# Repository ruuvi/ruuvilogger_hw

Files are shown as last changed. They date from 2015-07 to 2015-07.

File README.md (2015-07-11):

# RuuviLogger: Open-Source GPS logging device

You can find RuuviLogger related hardware design files from this repository. Design is almost finished, but not 100% ready. If RuuviLogger project continues, Rev.A version will be probably deprecated.

All the design files are licensed under Attribution-ShareAlike 4.0 International (CC BY-SA 4.0). Copyright: Lauri Jämsä, Ruuvi Innovations Ltd.

More info (a few blog posts) about the project: http://ruuvi.com/blog

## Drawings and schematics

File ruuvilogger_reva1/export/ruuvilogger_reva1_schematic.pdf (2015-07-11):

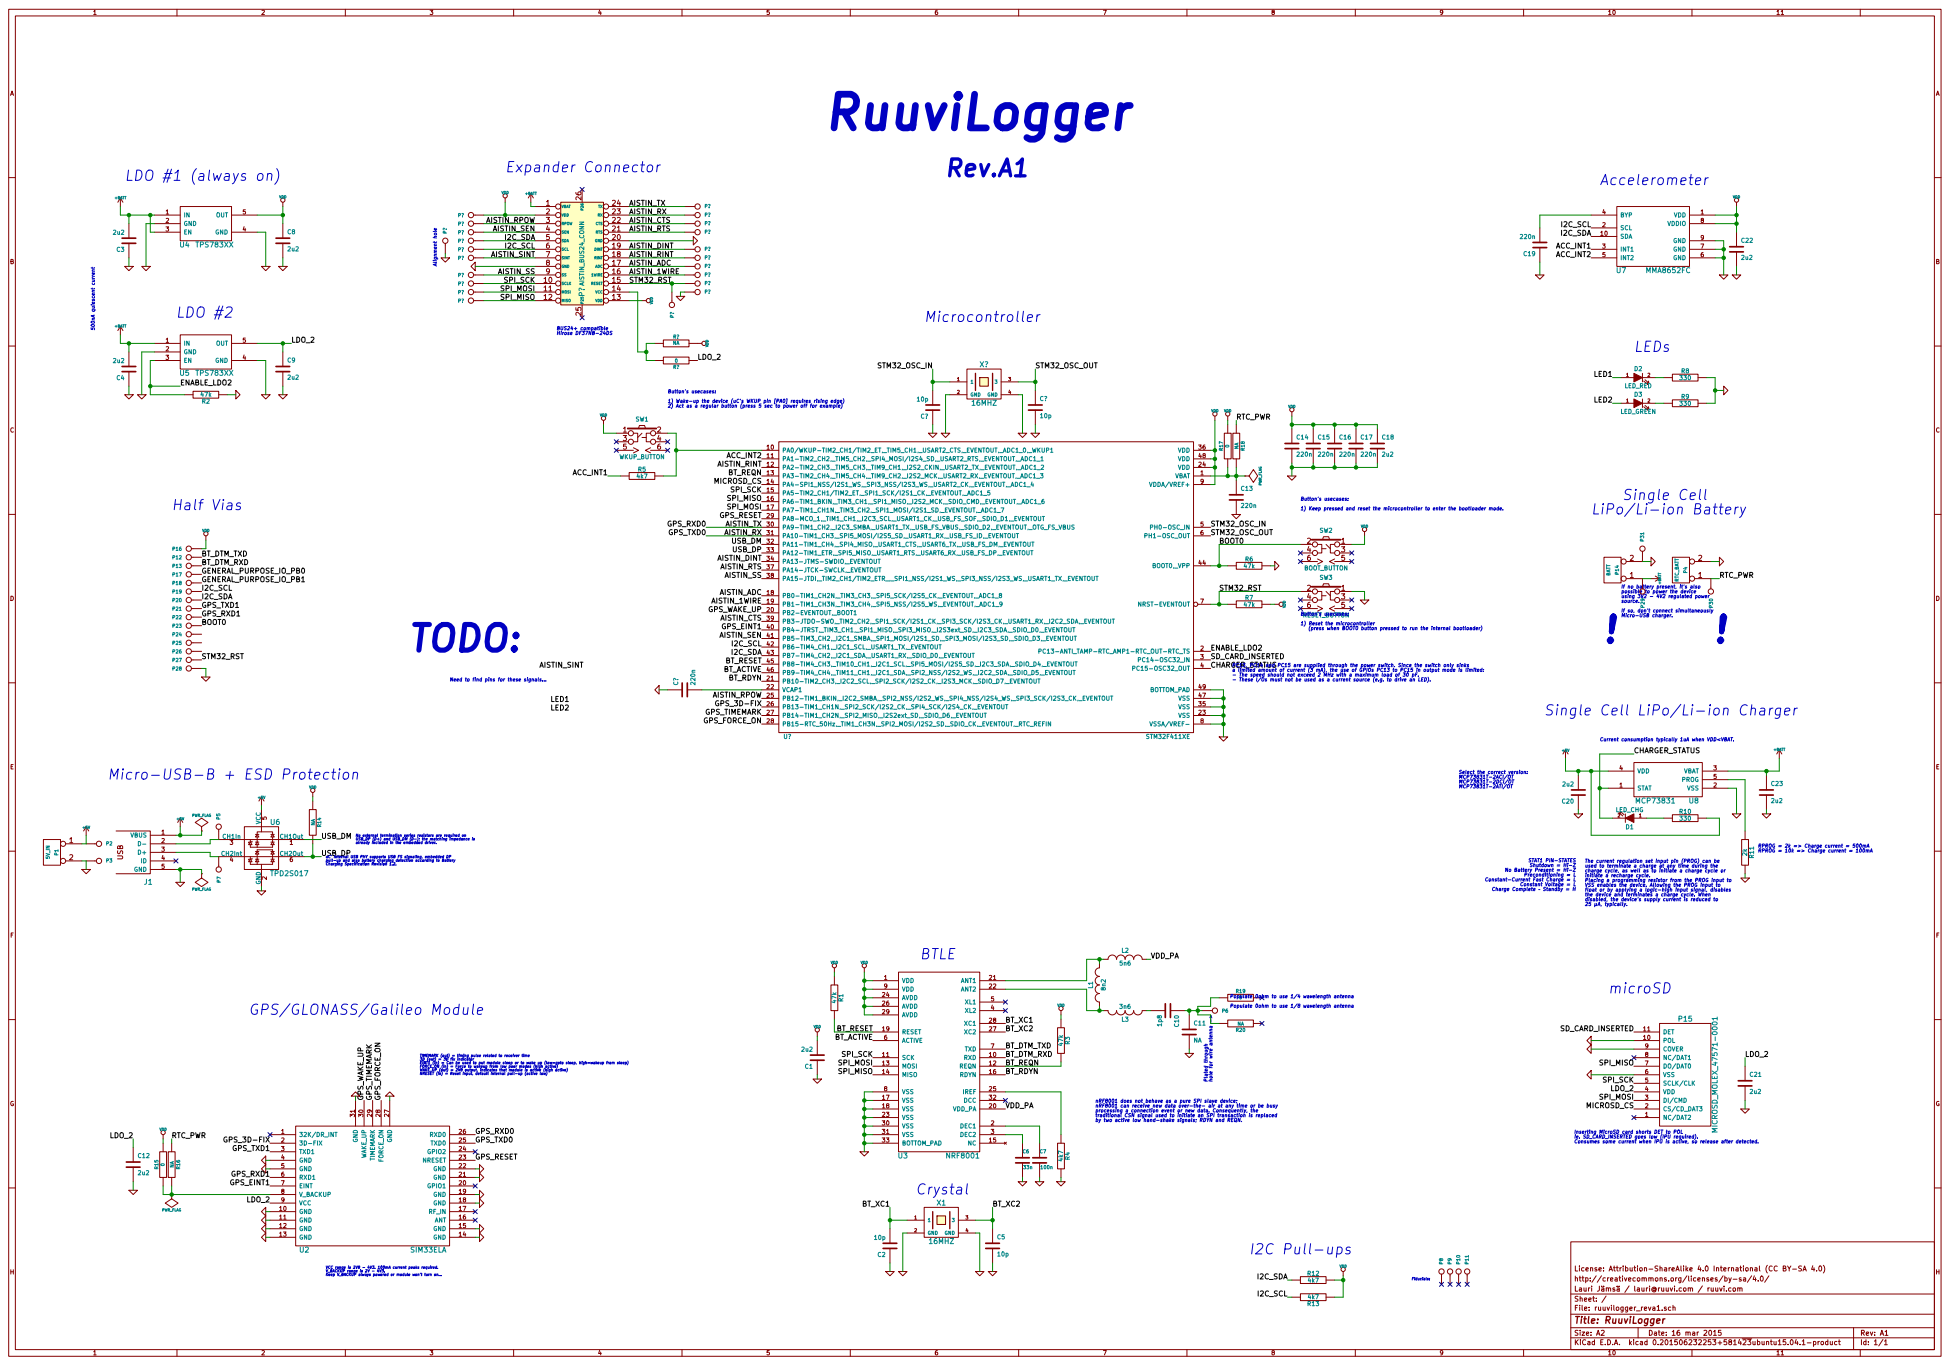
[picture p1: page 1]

PC13, PC14 and PC15 are supplied through the power switch. Since the switch only sinks a limited amount of current (3 mA), the use of GPIOs PC13 to PC15 in output mode is limited: - The speed should not exceed 2 MHz with a maximum load of 30 pF. - These I/Os must not be used as a current source (e.g. to drive an LED). STM32_OSC_OUT

If so, don't connect simultaneously Micro-USB charger. Single Cell
LiPo/Li-ion Battery

(press when BOOT0 button pressed to run the internal bootloader) Button's usecases: 1) Keep pressed and reset the microcontroller to enter the bootloader mode. Need to find pins for these signals... GPS_RXD1

If no battery present, it's also
possible to power the device
using 3V2 - 4V2 regulated power source.

Button's usecases: 1) Reset the microcontroller

Single Cell LiPo/Li-ion Charger

Micro-USB-B + ESD Protection

USB_DP
uC' internal USB PHY supports USB FS signaling, embedded DP
pull-up and also battery charging detection according to Battery Charging Specification Revision 1.2.

The current regulation set input pin (PROG) can be
used to terminate a charge at any time during the
charge cycle, as well as to initiate a charge cycle or
initiate a recharge cycle. Placing a programming resistor from the PROG input to VSS enables the device. Allowing the PROG input to

float or by applying a logic-high input signal, disables
the device and terminates a charge cycle. When
disabled, the devices supply current is reduced to

Populate 0ohm to use 1/4 wavelength antenna Populate 0ohm to use 1/8 wavelength antenna Plated through hole for wire antenna ->

GPS/GLONASS/Galileo Module

ie. SD_CARD_INSERTED goes low (IPU required). Consumes some current when IPU is active, so release after detected. SD_CARD_INSERTED

by two active low hand-shake signals; RDYN and REQN. BT_DTM_TXD
BT_DTM_RXD
BT_REQN
BT_RDYN

TIMEMARK (out) = timing pulse related to receiver time
3D (out) = 3D fix indicator EINT1 (in) = Can be used to put module sleep or to wake up (low=goto sleep, high=wakeup from sleep) FORCE_ON (in) = Force to wakeup from low poer modes (high active) WAKE_UP (out) = 2V8 output, indicates that module is active (high active) NRESET (in) = Reset input, default internal pull-up (active low)

nRF8001 does not behave as a pure SPI slave device; nRF8001 can receive new data over-the- air at any time or be busy processing a connection event or new data. Consequently, the

traditional CSN signal used to initiate an SPI transaction is replaced

Inserting MicroSD card shorts DET to POL

VCC range is 2V8 - 4V3. 100mA current peaks required. V_BACKUP range is 2V - 4V3. Keep V_BACKUP always powered or module won't turn on...

License: Attribution-ShareAlike 4.0 International (CC BY-SA 4.0)
http://creativecommons.org/licenses/by-sa/4.0/
File: ruuvilogger_reva1.sch Sheet: / Lauri Jämsä / lauri@ruuvi.com / ruuvi.com

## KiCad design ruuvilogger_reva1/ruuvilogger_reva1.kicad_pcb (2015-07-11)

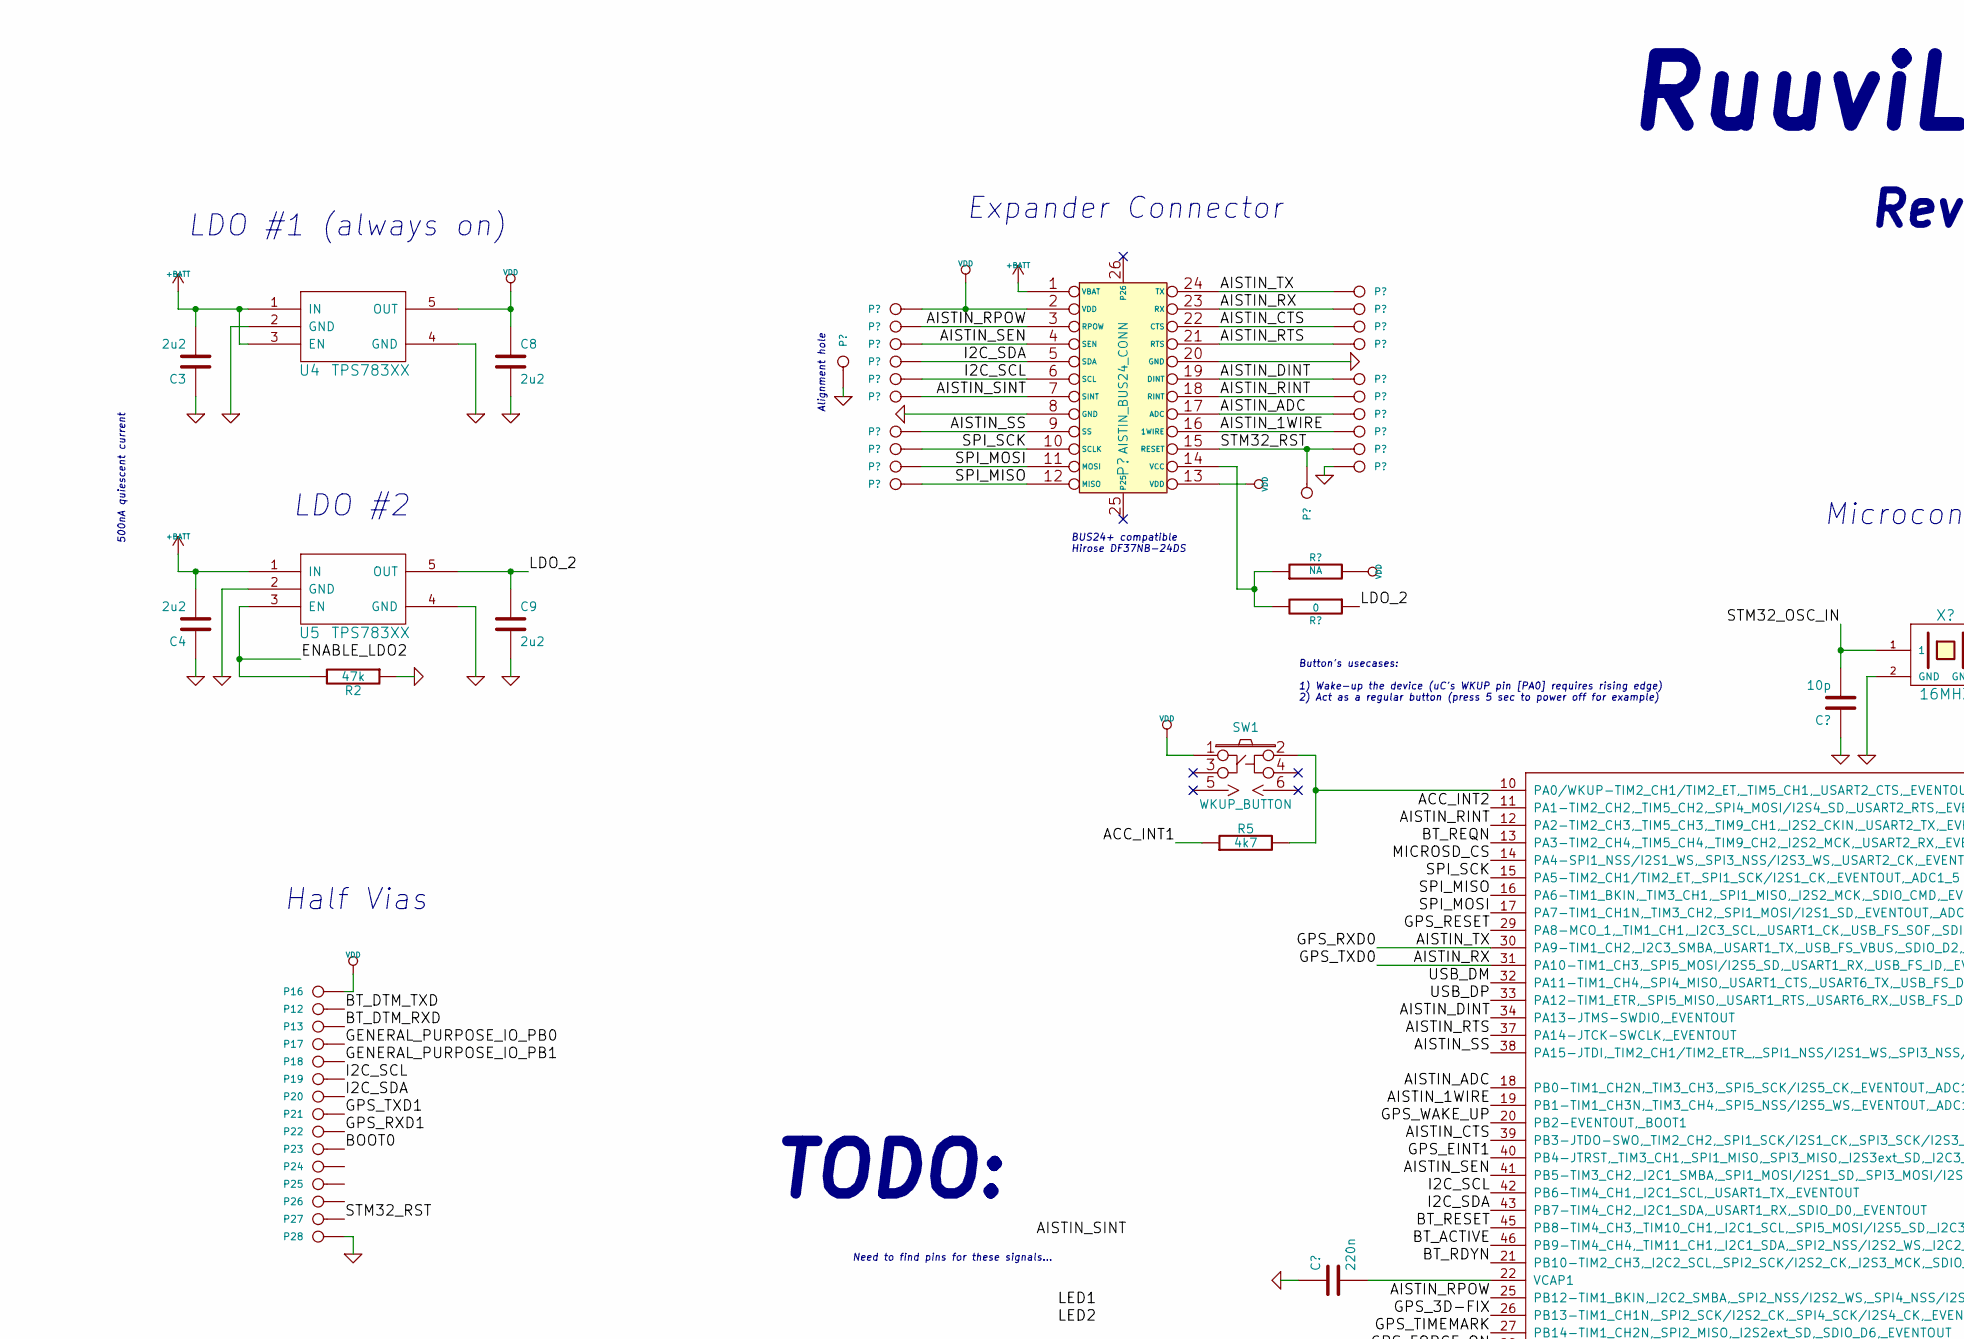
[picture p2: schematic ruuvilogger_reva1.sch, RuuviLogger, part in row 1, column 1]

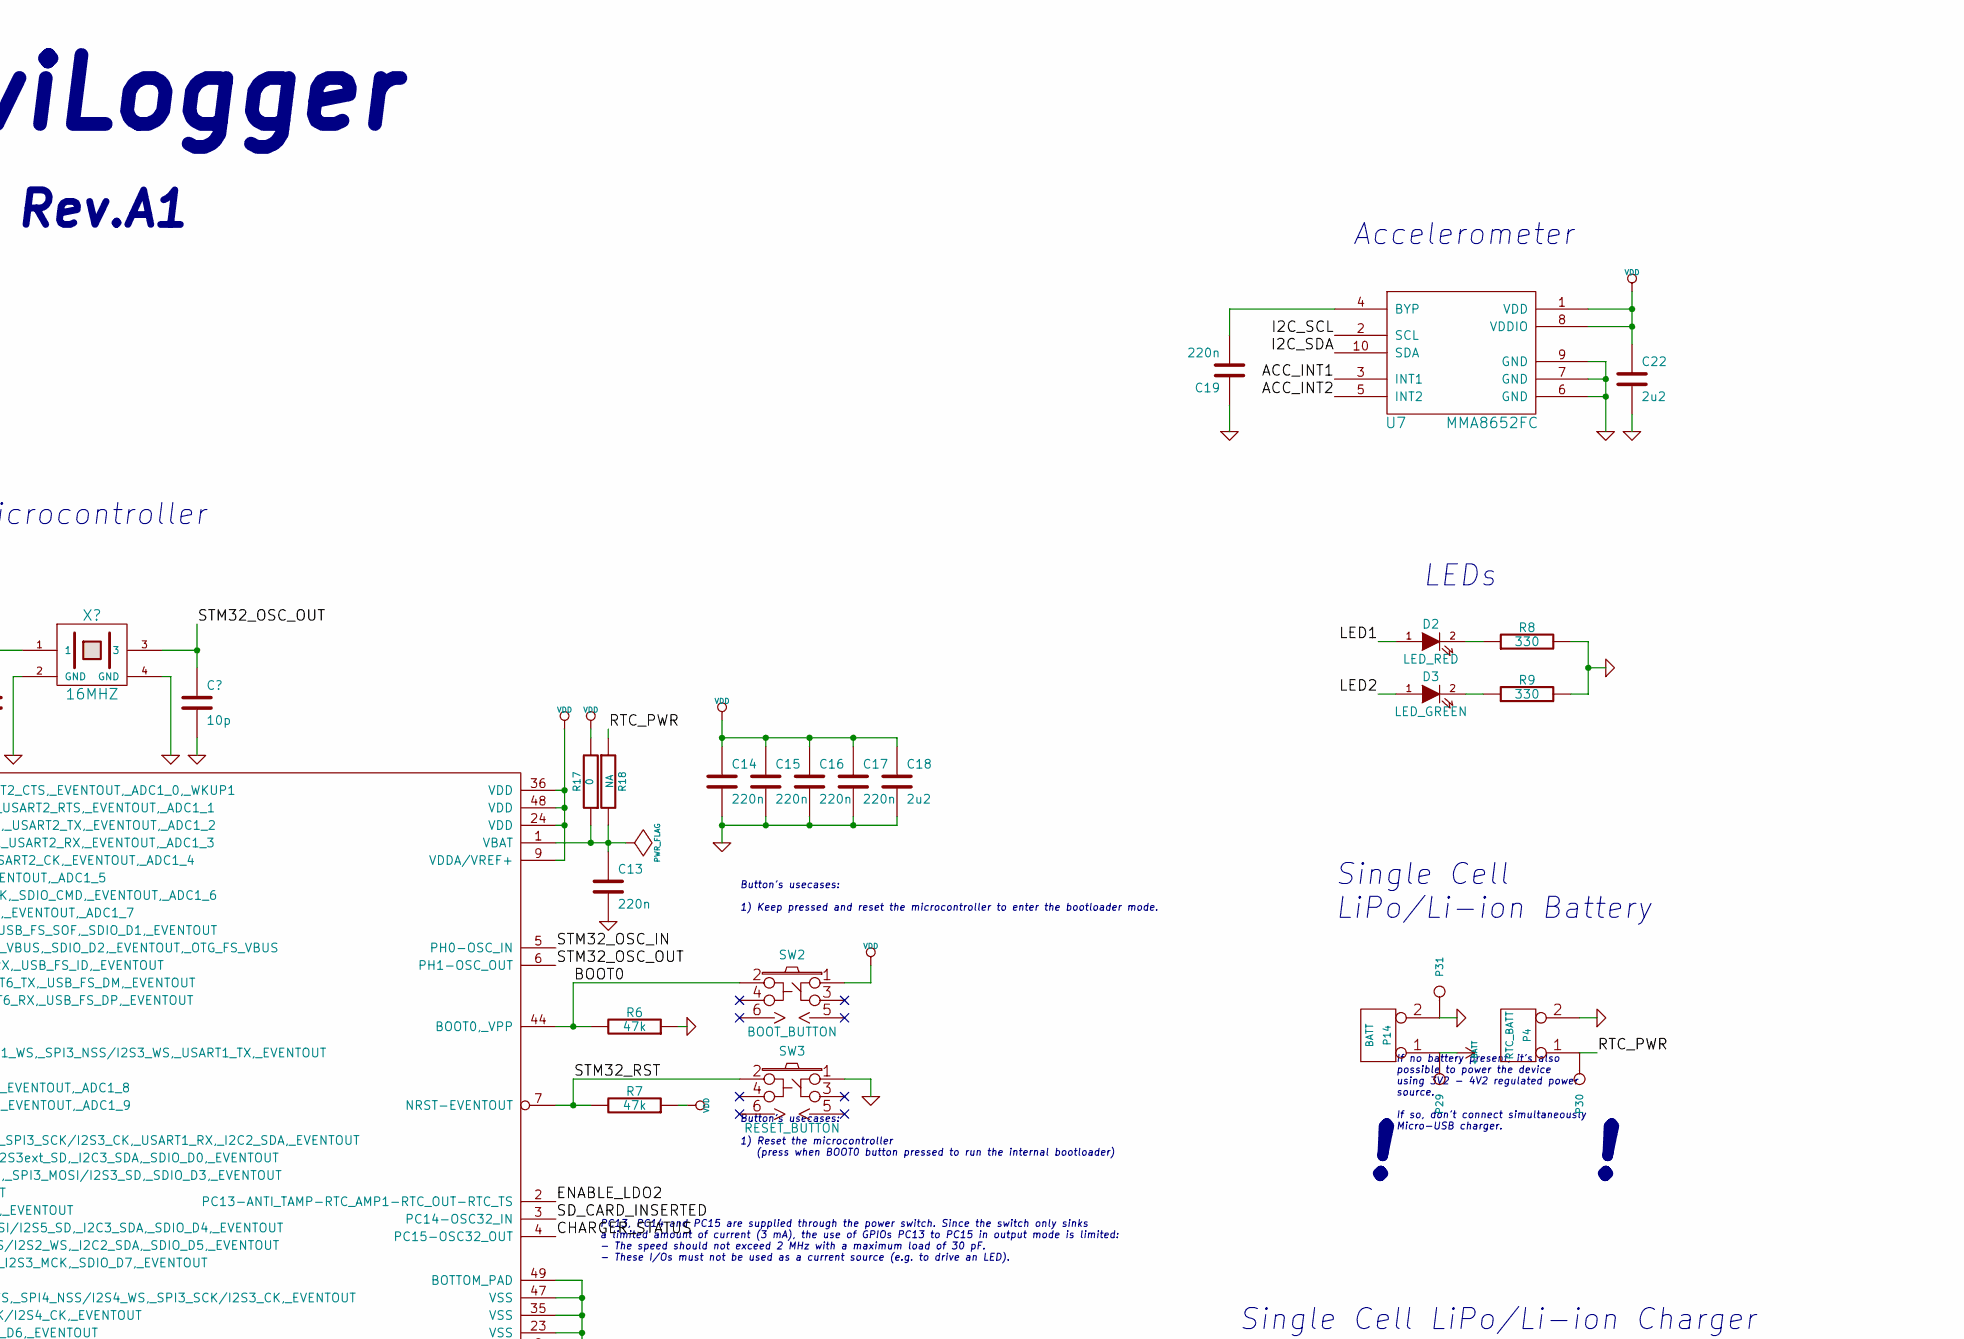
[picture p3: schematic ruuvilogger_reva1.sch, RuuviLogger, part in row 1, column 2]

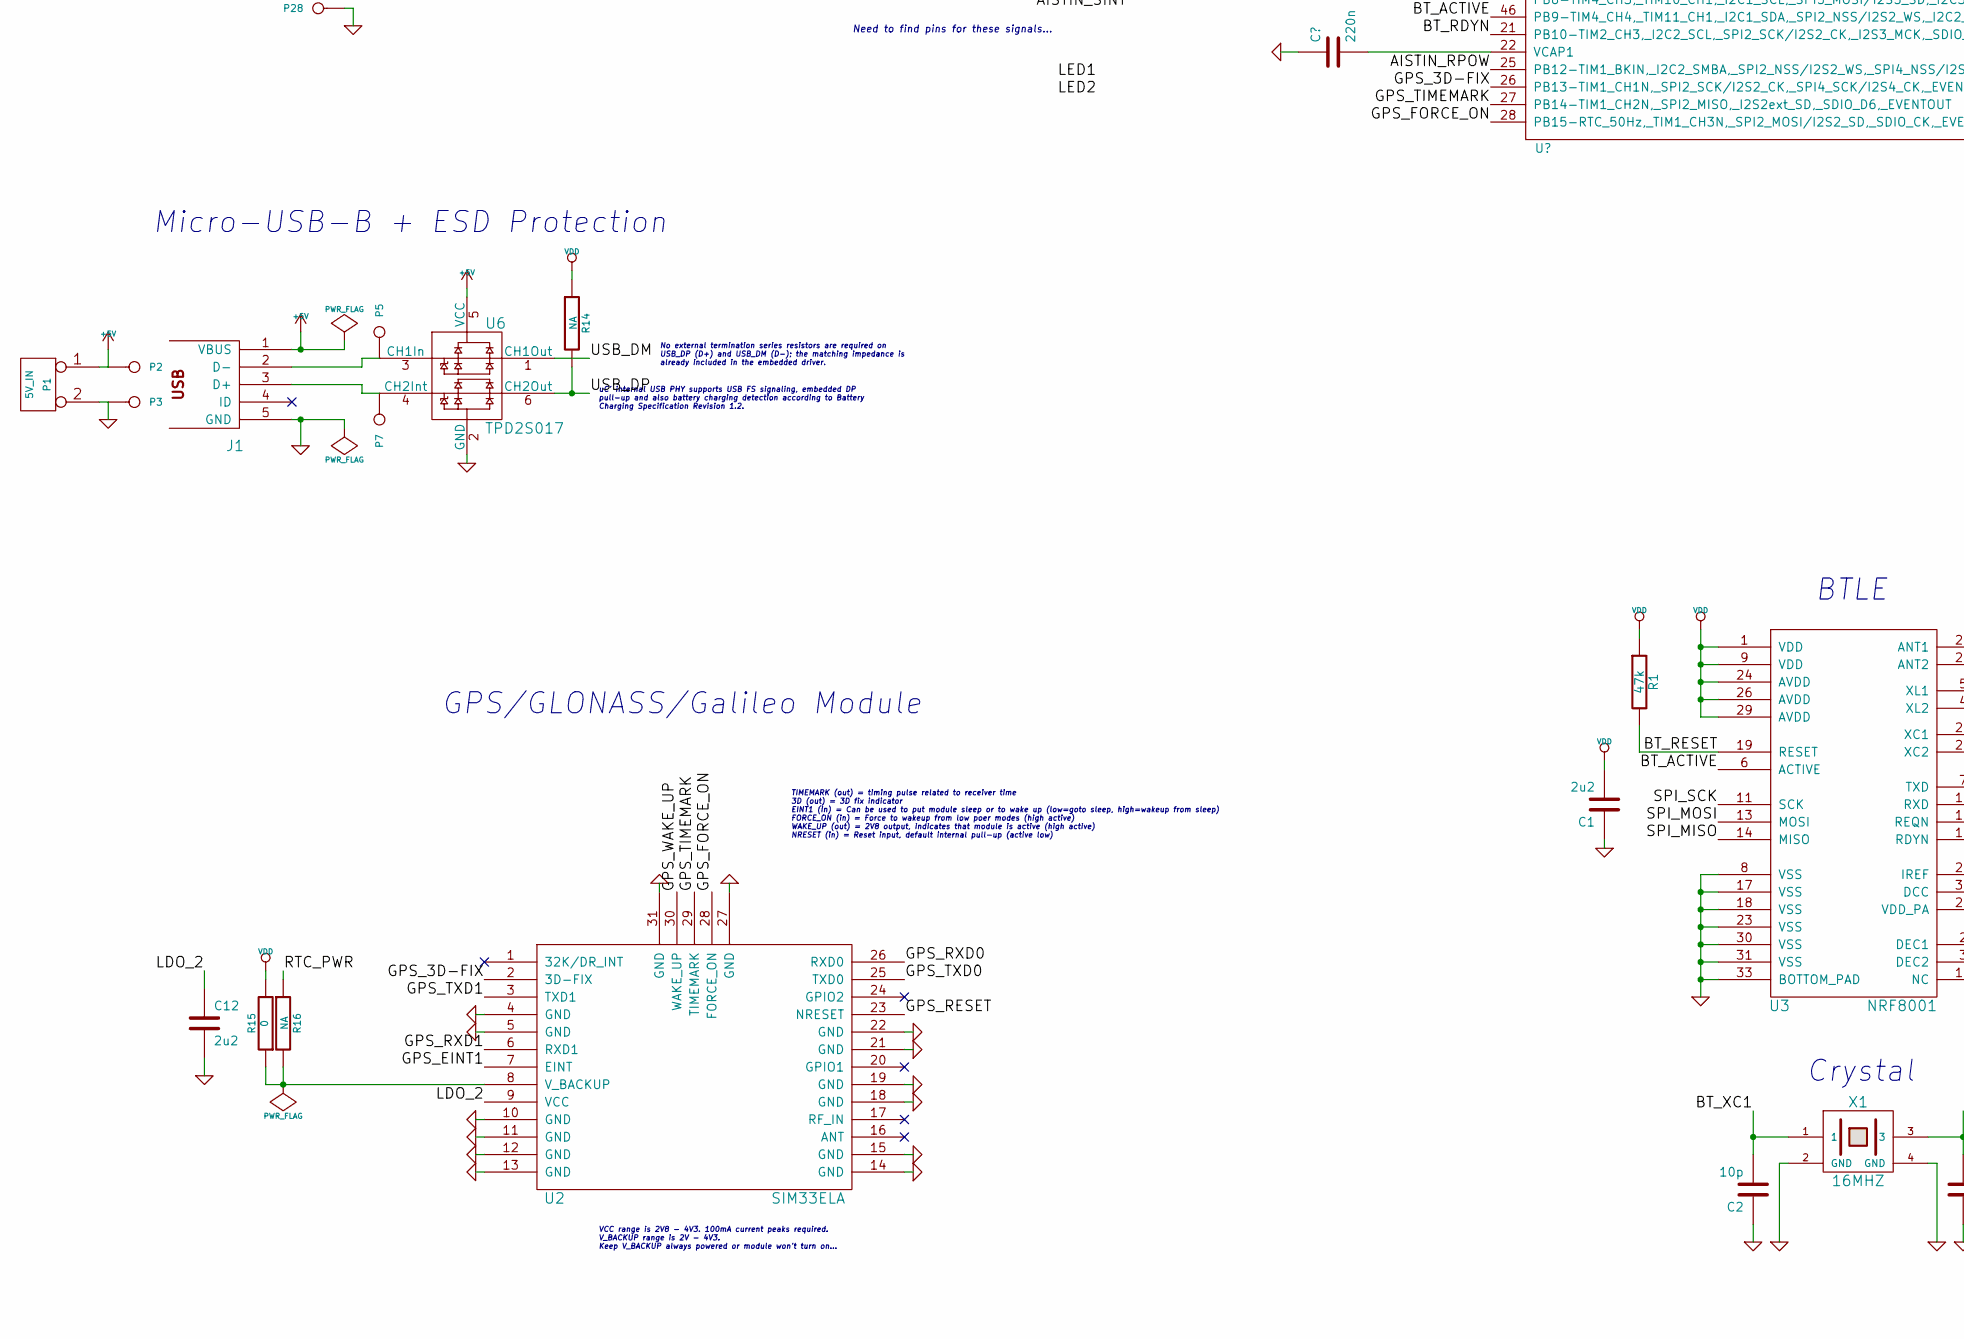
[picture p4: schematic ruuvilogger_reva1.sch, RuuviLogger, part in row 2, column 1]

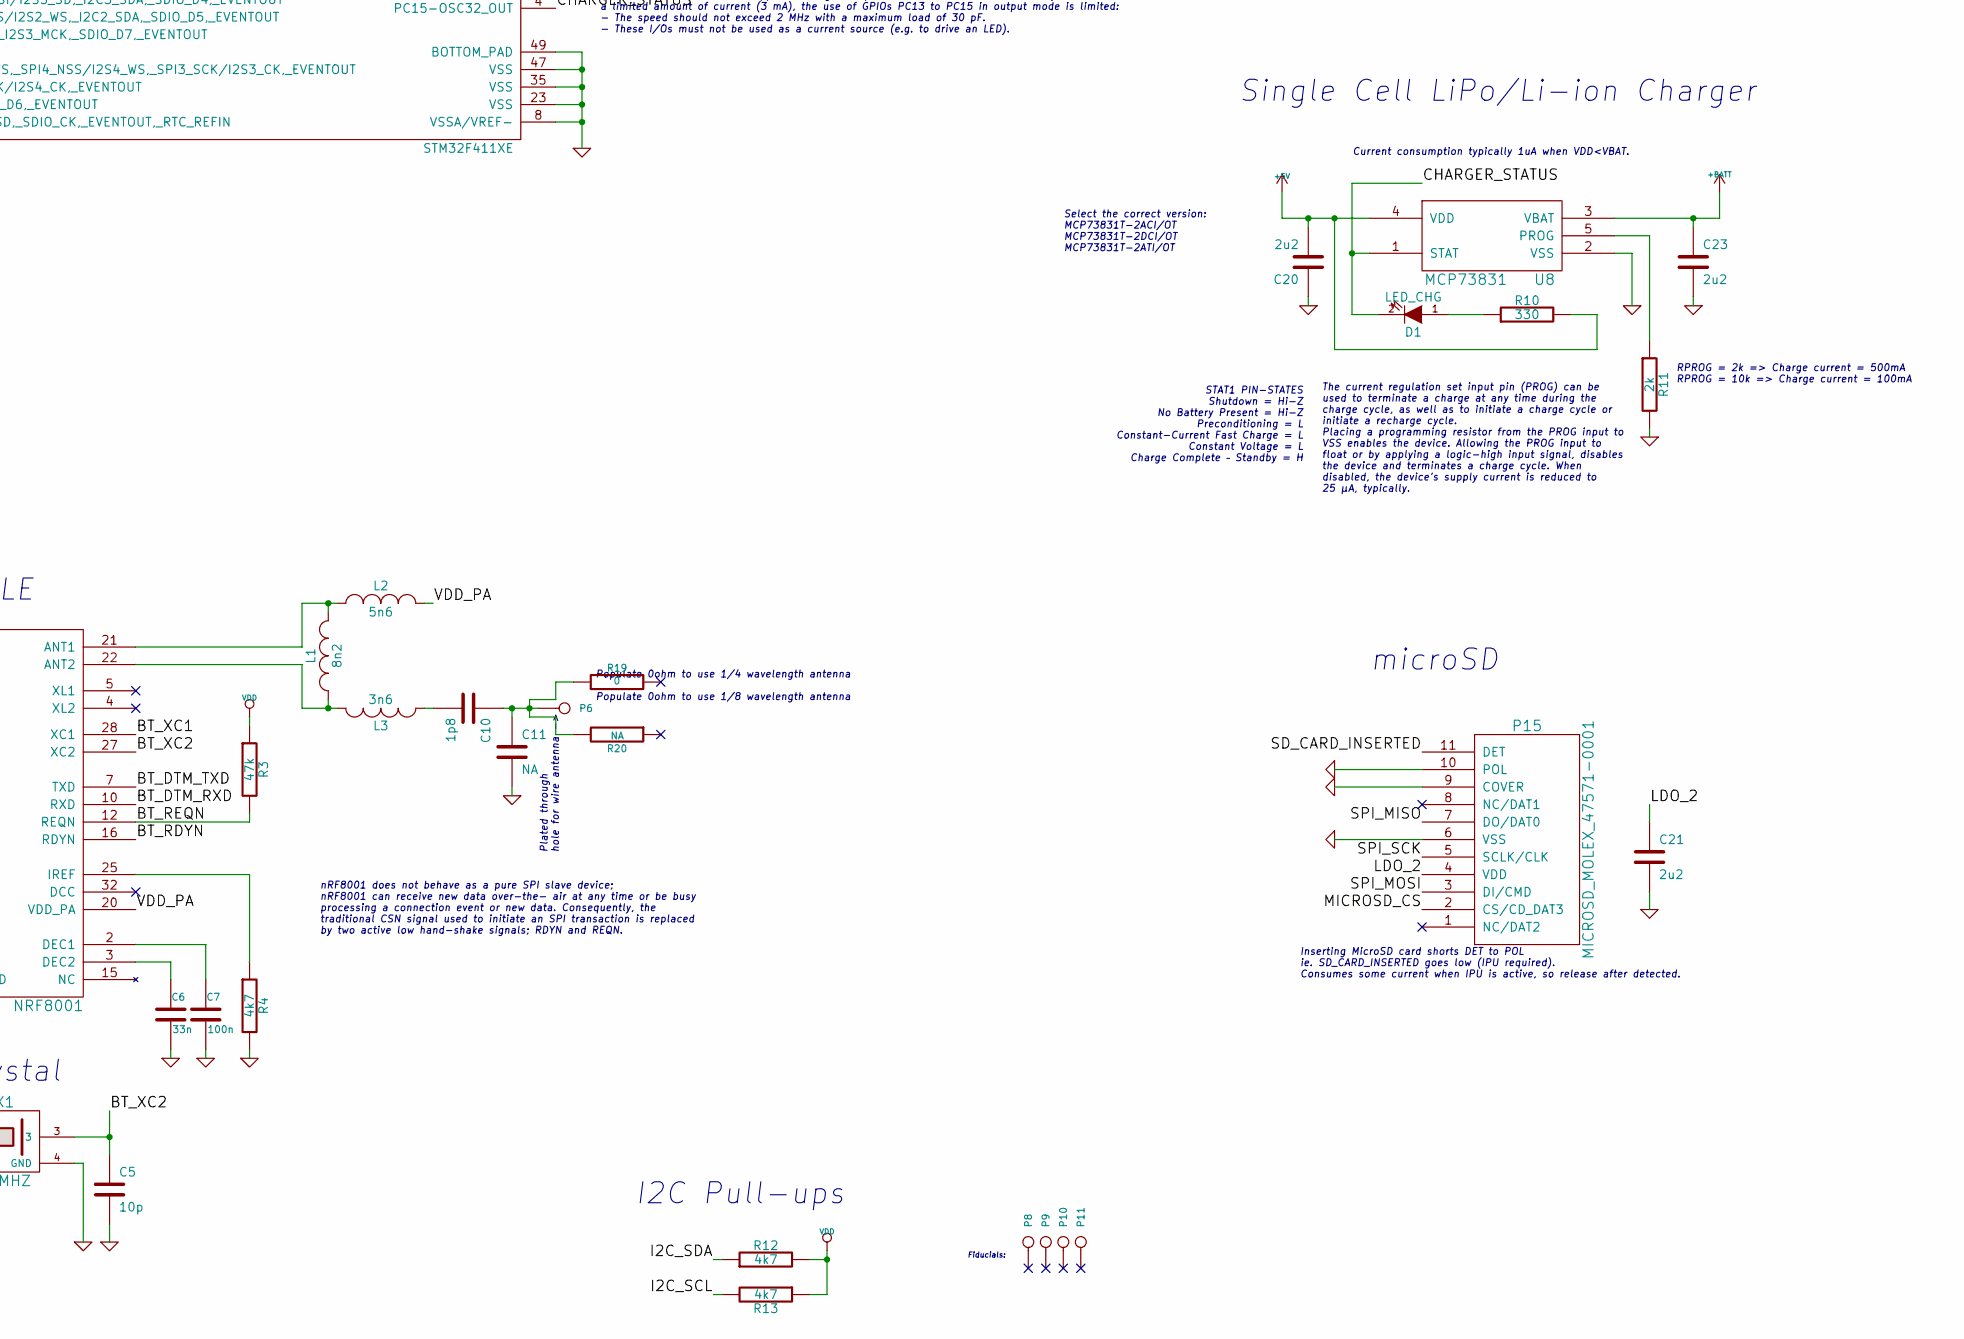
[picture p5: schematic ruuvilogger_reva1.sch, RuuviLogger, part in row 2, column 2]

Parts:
C1, C3, C4, C8, C9, C12, C18, C20, C21, C22, C23: 2u2
C2, C5: 10p
C6: 33n
C7: 100n
C10: 1p8
C11: NA
C13, C14, C15, C16, C17, C19: 220n
D1: LED_CHG
D2: LED_RED
D3: LED_GREEN
J1: USB_MICRO_B
L1: 8n2
L2: 5n6
L3: 3n6
P1: 5V_IN
P2: PIN_5VIN
P3, P28: PIN_GND
P4: RTC_BATT
P5: PIN_USB-
P6: BT_ANT_PLATED_HOLE
P7: PIN_USB+
P8, P9, P10, P11: FIDU
P12: PIN_BT_DTM_TXD
P13: PIN_BT_DTM_RXD
P14: BATT
P15: MICROSD_MOLEX_47571-0001
P16: PIN_VDD
P17: PIN_PB0
P18: PIN_PB1
P19: PIN_I2C_SCL
P20: PIN_I2C_SDA
P21: PIN_GPS_TXD1
P22: PIN_GPS_RXD1
P23: PIN_BOOT0
P24: PIN_USART_RX
P25: PIN_SWCLK_USART_TX
P26: PIN_SWDIO
P27: PIN_STM32_RST
P29: PIN_BATT+
P30: PIN_RTC_PWR
P31: PIN_BATT_GND
R1, R2, R3, R6, R7: 47k
R4, R5, R12, R13: 4k7
R8, R9, R10: 330
R11: 2k
R14, R16, R18, R20: NA
R15, R17, R19: 0
SW1: WKUP_BUTTON
SW2: BOOT_BUTTON
SW3: RESET_BUTTON
U2: SIM33ELA
U3: NRF8001
U4, U5: TPS783XX
U6: TPD2S017
U7: MMA8652FC
U8: MCP73831
X1: 16MHZ

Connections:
+5V: C20.2, J1.1 (VBUS), P1.1, P2.1, R10.2, U6.5 (VCC), U8.4 (VDD)
+BATT: C3.2, C4.2, C23.1, P14.1, P29.1, U4.1 (IN), U4.3 (EN), U5.1 (IN), U8.3 (VBAT)
/ACC_INT1: R5.1, U7.3 (INT1)
/ACC_INT2: U7.5 (INT2); also elsewhere on the board
/BOOT0: P23.1, R6.2, SW2.2; also elsewhere on the board
/BT_ACTIVE: U3.6 (ACTIVE); also elsewhere on the board
/BT_DTM_RXD: P13.1, U3.10 (RXD)
/BT_DTM_TXD: P12.1, U3.7 (TXD)
/BT_RDYN: U3.16 (RDYN); also elsewhere on the board
/BT_REQN: R3.2, U3.12 (REQN); also elsewhere on the board
/BT_RESET: R1.2, U3.19 (RESET); also elsewhere on the board
/BT_XC1: C2.2, U3.28 (XC1), X1.1
/BT_XC2: C5.1, U3.27 (XC2), X1.3
/CHARGER_STATUS: D1.2 (K), U8.1 (STAT); also elsewhere on the board
/ENABLE_LDO2: R2.2, U5.3 (EN); also elsewhere on the board
/GENERAL_PURPOSE_IO_PB0: P17.1; also elsewhere on the board
/GENERAL_PURPOSE_IO_PB1: P18.1; also elsewhere on the board
/GPS_3D-FIX: U2.2 (3D-FIX); also elsewhere on the board
/GPS_EINT1: U2.7 (EINT); also elsewhere on the board
/GPS_FORCE_ON: U2.28 (FORCE_ON); also elsewhere on the board
/GPS_RESET: U2.23 (NRESET); also elsewhere on the board
/GPS_RXD0: U2.26 (RXD0); also elsewhere on the board
/GPS_RXD1: P22.1, U2.6 (RXD1)
/GPS_TIMEMARK: U2.29 (TIMEMARK); also elsewhere on the board
/GPS_TXD0: U2.25 (TXD0); also elsewhere on the board
/GPS_TXD1: P21.1, U2.3 (TXD1)
/GPS_WAKE_UP: U2.30 (WAKE_UP); also elsewhere on the board
/I2C_SCL: P19.1, R13.2, U7.2 (SCL); also elsewhere on the board
/I2C_SDA: P20.1, R12.1, U7.10 (SDA); also elsewhere on the board
/LDO_2: C9.1, C12.1, C21.1, P15.4 (VDD), U2.9 (VCC), U5.5 (OUT)
/LED1: D2.1 (A); also elsewhere on the board
/LED2: D3.1 (A); also elsewhere on the board
/MICROSD_CS: P15.2 (CS/CD_DAT3); also elsewhere on the board
/RTC_PWR: P4.1, P30.1, R16.1, R18.1
/SD_CARD_INSERTED: P15.11 (DET); also elsewhere on the board
/SPI_MISO: P15.7 (DO/DAT0), U3.14 (MISO); also elsewhere on the board
/SPI_MOSI: P15.3 (DI/CMD), U3.13 (MOSI); also elsewhere on the board
/SPI_SCK: P15.5 (SCLK/CLK), U3.11 (SCK); also elsewhere on the board
/STM32_RST: P27.1, R7.2, SW3.2; also elsewhere on the board
/SWCLK-USART_TX_FOR_FLASHING/DEBUG: P25.1; also elsewhere on the board
/SWDIO: P26.1; also elsewhere on the board
/USART_RX_FOR_FLASHING/DEBUG: P24.1; also elsewhere on the board
/USB_DM: U6.1 (CH1Out); also elsewhere on the board
/USB_DP: R14.2, U6.6 (CH2Out); also elsewhere on the board
/VDD_PA: L2.2, U3.20 (VDD_PA)
GND: C1.1, C2.1, C3.1, C4.1, C5.2, C6.2, C7.2, C8.2, C9.2, C11.2, C12.2, C13.2, C14.2, C15.2, C16.2, C17.2, C18.2, C19.1, C20.1, C21.2, C22.2, C23.2, J1.5 (GND), P1.2 (PM), P3.1, P4.2 (PM), P14.2 (PM), P15.6 (VSS), P15.9 (COVER), P15.10 (POL), P28.1, P31.1, R2.1, R4.2, R6.1, R8.2, R9.2, R11.2, SW3.1, U2.4 (GND), U2.5 (GND), U2.10 (GND), U2.11 (GND), U2.12 (GND), U2.13 (GND), U2.14 (GND), U2.15 (GND), U2.18 (GND), U2.19 (GND), U2.21 (GND), U2.22 (GND), U2.27 (GND), U2.31 (GND), U3.8 (VSS), U3.17 (VSS), U3.18 (VSS), U3.23 (VSS), U3.30 (VSS), U3.31 (VSS), U3.33 (BOTTOM_PAD), U4.2 (GND), U4.4 (GND), U5.2 (GND), U5.4 (GND), U6.2 (GND), U7.6 (GND), U7.7 (GND), U7.9 (GND), U8.2 (VSS), X1.2 (GND), X1.4 (GND); also elsewhere on the board
unnamed: C10.2, L3.1
unnamed: L1.1, L3.2, U3.22 (ANT2)
unnamed: R4.1, U3.25 (IREF)
unnamed: C6.1, U3.3 (DEC2)
unnamed: C7.1, U3.2 (DEC1)
unnamed: L1.2, L2.1, U3.21 (ANT1)
unnamed: J1.2 (D-), P5.1, U6.3 (CH1In)
unnamed: J1.3 (D+), P7.1, U6.4 (CH2Int)
unnamed: D3.2 (K), R9.1
unnamed: D2.2 (K), R8.1
unnamed: C19.2, U7.4 (BYP)
unnamed: D1.1 (A), R10.1
unnamed: R11.1, U8.5 (PROG)
unnamed: R15.1, R16.2, U2.8 (V_BACKUP)
unnamed 60: C13.1, R17.1, R18.2; also elsewhere on the board
unnamed: C10.1, C11.1, P6.1, R19.1, R20.2
unnamed 62: R5.2, SW1.2; also elsewhere on the board
VDD: C1.2, C8.1, C14.1, C15.1, C16.1, C17.1, C18.1, C22.1, P16.1, R1.1, R3.1, R7.1, R12.2, R13.1, R14.1, R15.2, R17.2, SW1.1, SW2.1, U3.1 (VDD), U3.9 (VDD), U3.24 (AVDD), U3.26 (AVDD), U3.29 (AVDD), U4.5 (OUT), U7.1 (VDD), U7.8 (VDDIO); also elsewhere on the board

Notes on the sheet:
GPS/GLONASS/Galileo Module
Inserting MicroSD card shorts DET to POL ie. SD_CARD_INSERTED goes low (IPU required). Consumes some current when IPU is active, so release after detected.
! !
If no battery present, it's also possible to power the device using 3V2 - 4V2 regulated power source. If so, don't connect simultaneously Micro-USB charger.
Single Cell LiPo/Li-ion Battery
microSD
I2C Pull-ups
LEDs
Single Cell LiPo/Li-ion Charger
STAT1 PIN-STATES Shutdown = Hi-Z No Battery Present = Hi-Z Preconditioning = L Constant-Current Fast Charge = L Constant Voltage = L Charge Complete – Standby = H
The current regulation set input pin (PROG) can be used to terminate a charge at any time during the charge cycle, as well as to initiate a charge cycle or initiate a recharge cycle. Placing a programming resistor from the PROG input to VSS enables the device. Allowing the PROG input to float or by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
RPROG = 2k => Charge current = 500mA RPROG = 10k => Charge current = 100mA
Accelerometer
Crystal
500nA quiescent current
LDO #1 (always on)
Micro-USB-B + ESD Protection
LDO #2
Button's usecases: 1) Wake-up the device (uC's WKUP pin [PA0] requires rising edge) 2) Act as a regular button (press 5 sec to power off for example)
RuuviLogger
Rev.A1
Current consumption typically 1uA when VDD<VBAT.
Select the correct version: MCP73831T-2ACI/OT MCP73831T-2DCI/OT MCP73831T-2ATI/OT
Fiducials:
uC' internal USB PHY supports USB FS signaling, embedded DP pull-up and also battery charging detection according to Battery Charging Specification Revision 1.2.
BTLE
VCC range is 2V8 - 4V3. 100mA current peaks required. V_BACKUP range is 2V - 4V3. Keep V_BACKUP always powered or module won't turn on...
TIMEMARK (out) = timing pulse related to receiver time 3D (out) = 3D fix indicator EINT1 (in) = Can be used to put module sleep or to wake up (low=goto sleep, high=wakeup from sleep) FORCE_ON (in) = Force to wakeup from low poer modes (high active) WAKE_UP (out) = 2V8 output, indicates that module 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
Button's usecases: 1) Reset the microcontroller (press when BOOT0 button pressed to run the internal bootloader)
Button's usecases: 1) Keep pressed and reset the microcontroller to enter the bootloader mode.
Need to find pins for these signals...
nRF8001 does not behave as a pure SPI slave device; nRF8001 can receive new data over-the- air at any time or be busy processing a connection event or new data. Consequently, the traditional CSN signal used to initiate an SPI transaction is replaced by two active low hand-shake signals; RDYN and RE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
No external termination series resistors are required on USB_DP (D+) and USB_DM (D-); the matching impedance is already included in the embedded driver.
Populate 0ohm to use 1/4 wavelength antenna Populate 0ohm to use 1/8 wavelength antenna
Plated through hole for wire antenna ->
Half Vias
Microcontroller
BUS24+ compatible Hirose DF37NB-24DS
Expander Connector
Alignment hole

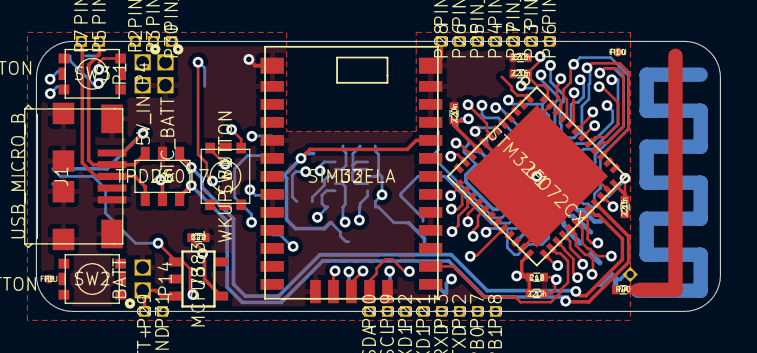
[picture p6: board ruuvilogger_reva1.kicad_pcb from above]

Board: 4 copper layers, 38.0 x 15.0 mm, 93 parts (0 on the bottom side), 64 nets.

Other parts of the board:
U1: STM32F072CX; UFQFPN48_BOTPAD

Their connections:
/ACC_INT2: U1.11; also elsewhere on the board
/BOOT0: U1.44; also elsewhere on the board
/BT_ACTIVE: U1.46; also elsewhere on the board
/BT_RDYN: U1.40; also elsewhere on the board
/BT_REQN: U1.39; also elsewhere on the board
/BT_RESET: U1.45; also elsewhere on the board
/CHARGER_STATUS: U1.25; also elsewhere on the board
/ENABLE_LDO2: U1.30; also elsewhere on the board
/GENERAL_PURPOSE_IO_PB0: U1.18; also elsewhere on the board
/GENERAL_PURPOSE_IO_PB1: U1.19; also elsewhere on the board
/GPS_3D-FIX: U1.26; also elsewhere on the board
/GPS_EINT1: U1.31; also elsewhere on the board
/GPS_FORCE_ON: U1.28; also elsewhere on the board
/GPS_RESET: U1.29; also elsewhere on the board
/GPS_RXD0: U1.12; also elsewhere on the board
/GPS_TIMEMARK: U1.27; also elsewhere on the board
/GPS_TXD0: U1.13; also elsewhere on the board
/GPS_WAKE_UP: U1.20; also elsewhere on the board
/I2C_SCL: U1.42; also elsewhere on the board
/I2C_SDA: U1.43; also elsewhere on the board
/LED1: U1.21; also elsewhere on the board
/LED2: U1.22; also elsewhere on the board
/MICROSD_CS: U1.14; also elsewhere on the board
/SD_CARD_INSERTED: U1.41; also elsewhere on the board
/SPI_MISO: U1.16; also elsewhere on the board
/SPI_MOSI: U1.17; also elsewhere on the board
/SPI_SCK: U1.15; also elsewhere on the board
/STM32_RST: U1.7; also elsewhere on the board
/SWCLK-USART_TX_FOR_FLASHING/DEBUG: U1.37; also elsewhere on the board
/SWDIO: U1.34; also elsewhere on the board
/USART_RX_FOR_FLASHING/DEBUG: U1.38; also elsewhere on the board
/USB_DM: U1.32; also elsewhere on the board
/USB_DP: U1.33; also elsewhere on the board
GND: U1.8, U1.23, U1.35, U1.47, U1.49; also elsewhere on the board
unnamed 60: U1.1; also elsewhere on the board
unnamed 62: U1.10; also elsewhere on the board
VDD: U1.9, U1.24, U1.36, U1.48; also elsewhere on the board

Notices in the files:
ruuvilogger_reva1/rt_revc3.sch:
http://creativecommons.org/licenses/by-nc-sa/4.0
